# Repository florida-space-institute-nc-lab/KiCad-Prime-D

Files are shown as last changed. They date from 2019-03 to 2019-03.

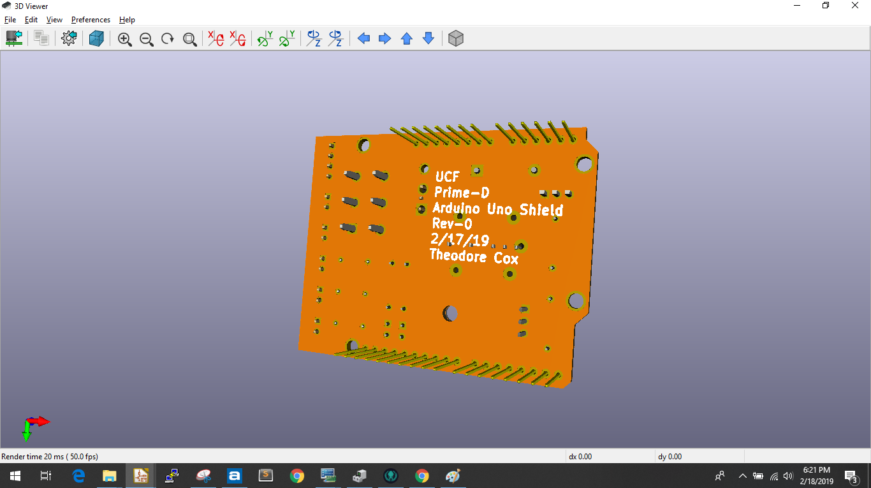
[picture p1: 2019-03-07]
documents/pictures/3dView_021819_1.png

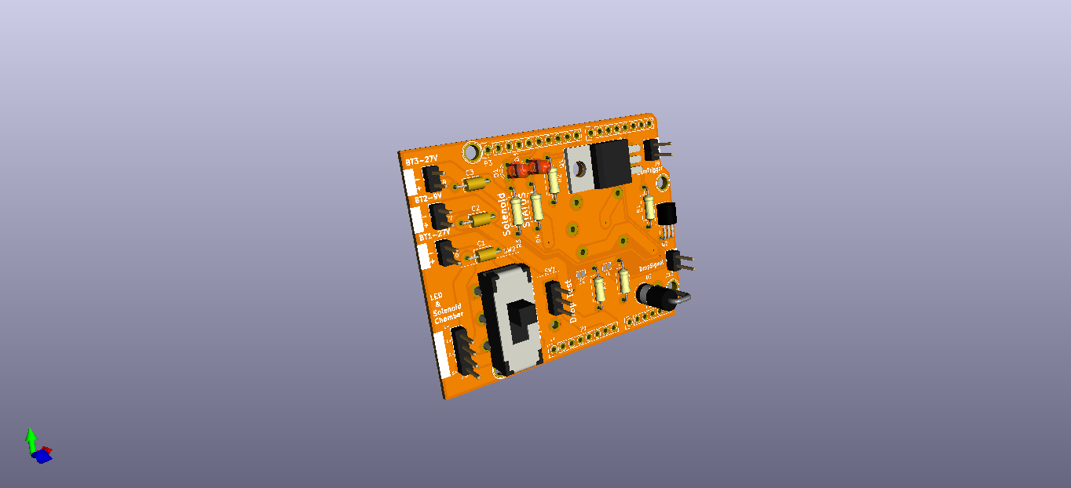
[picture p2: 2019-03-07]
documents/pictures/3dView_021819_3.png

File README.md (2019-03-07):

# Prime-D
This KiCad project includes both the schematic and pcb-layout for FSI drop tower project "Prime-D".  This circuit board should be treated as an Arduino "Shield" and be placed on top of the Arduino Uno socket.



## Usage
This project requires KiCad Version 5.0 and after to use.

## Documents Folder
The documents folder contains;
  * [the bill of materials (BOM)](/KiCad%20Projects/PRIME-D/documents/BOM/)
  * [all of the components datasheets](/KiCad%20Projects/PRIME-D/documents/datasheets/)
  * [gerber files](/KiCad%20Projects/PRIME-D/documents/Gerbers/)
  * [pictures](/KiCad%20Projects/PRIME-D/documents/pictures/)
  * [previous revisions](/KiCad%20Projects/PRIME-D/documents/Revisions/)
  * [pdf of both the schematic and pcb layout](/KiCad%20Projects/PRIME-D/documents/schematic_n_PCBlayout/)

## Coming Soon
Again please note that this Prime-D circuit board should be treated as an Arduino Uno shield.  The software to program the arduino will be added to this repo soon.

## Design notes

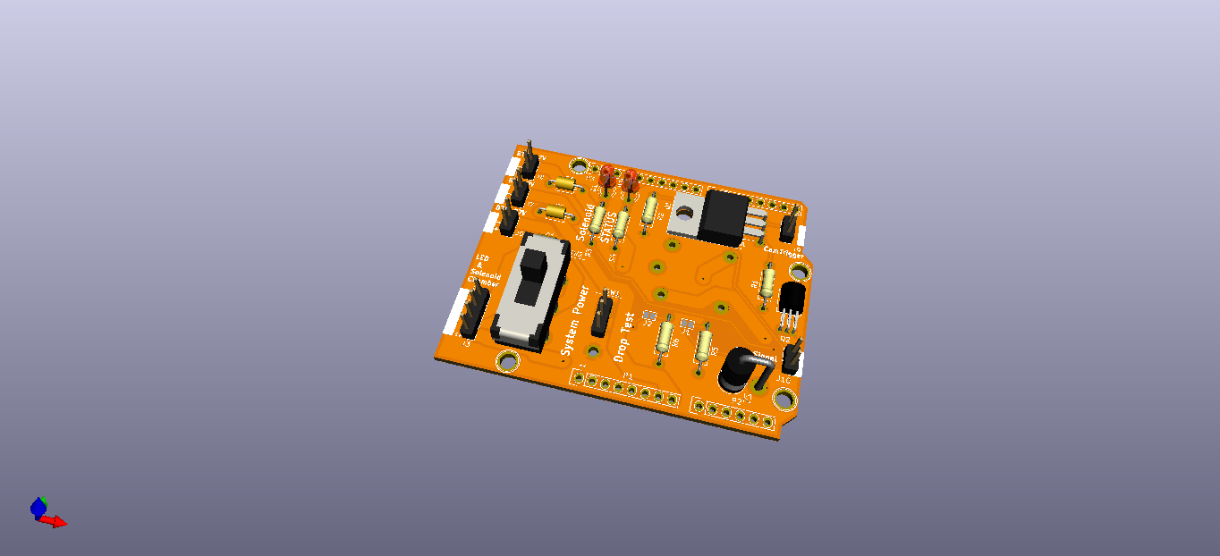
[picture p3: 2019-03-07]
documents/pictures/3dView_021819_2.png

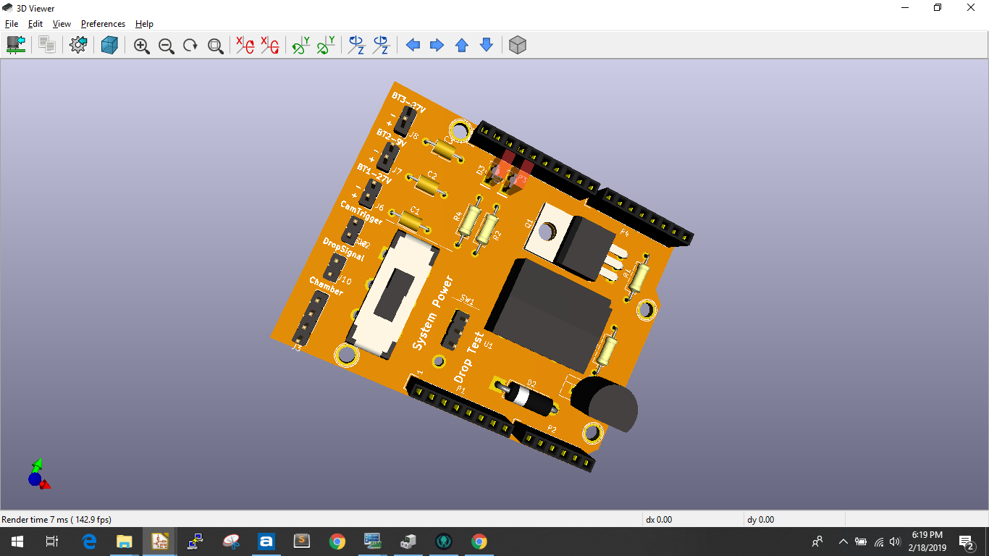
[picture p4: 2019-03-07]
documents/pictures/3dView_021819_0.png

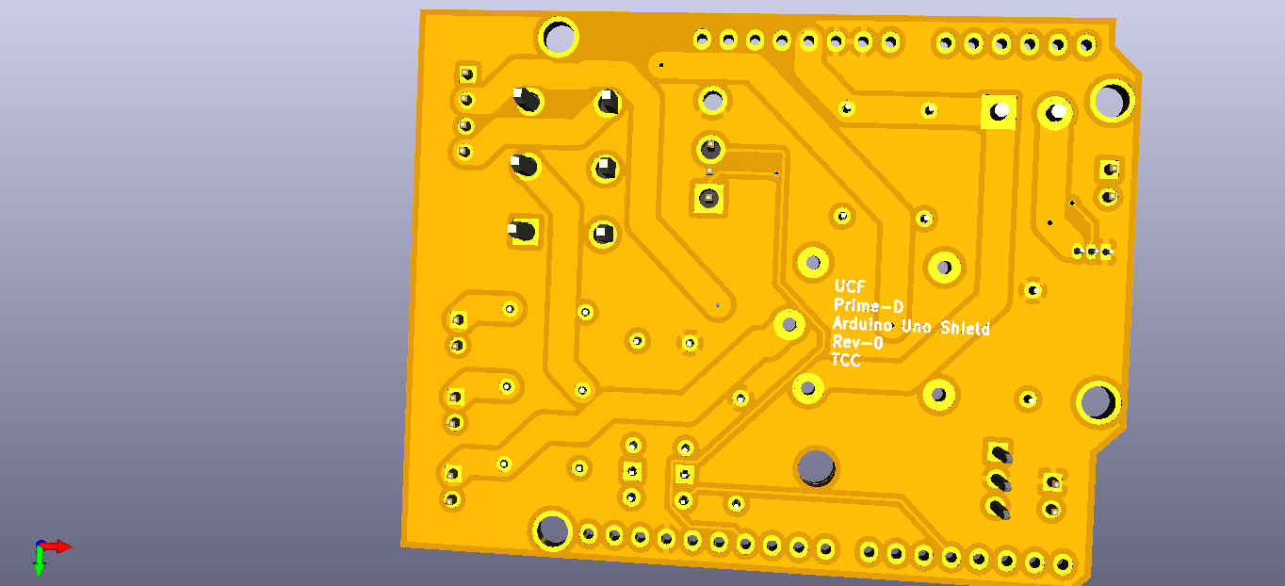
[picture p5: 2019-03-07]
documents/pictures/3dView_021819_4.png

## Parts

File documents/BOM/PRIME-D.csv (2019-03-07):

Title | PRIME D
Revision
Date | 2019-02-13
Generated | 2/18/2019 8:06:50 PM
Company | CMR
Comment 1 | This schematic was created after prototype board was created.
Comment 2 | This is only the KiCad author's interpretation of the electrical design of Prime-D.
Comment 3 | Author - Theodore Cox
Comment 4 | Date - 2/13/19
Total Parts | 33
Total Unique Parts | 23
Ref | Qty | Value | Footprint | Datasheet
C1 C2 C3 | 3 | 1uF | Capacitors_THT:C_Axial_L3.8mm_D2.6mm_P7.50mm_Horizontal | ~
D1 D3 | 2 | LED | LEDs:LED_D3.0mm | ~
D2 | 1 | 1N4007 | Diodes_THT:D_DO-201AD_P5.08mm_Vertical_AnodeUp | ~
J1 J2 | 2 | GS2 | Connectors:GS2
J3 | 1 | Connector_Chamber | Connector_PinHeader_2.54mm:PinHeader_1x04_P2.54mm_Vertical | ~
J6 | 1 | BAT1_27V | Connector_PinHeader_2.54mm:PinHeader_1x02_P2.54mm_Vertical | ~
J7 | 1 | BAT2_9V | Connector_PinHeader_2.54mm:PinHeader_1x02_P2.54mm_Vertical | ~
J8 | 1 | BAT3_27V | Connector_PinHeader_2.54mm:PinHeader_1x02_P2.54mm_Vertical | ~
J9 | 1 | CameraTrigger | Connector_PinHeader_2.54mm:PinHeader_1x02_P2.54mm_Vertical | ~
J10 | 1 | DropSignal | Connector_PinHeader_2.54mm:PinHeader_1x02_P2.54mm_Vertical | ~
K1 | 1 | ORWH-SH-105D1F | 000 | primeD-kiCad_pcbfootprints:Relay_SPST_ORWH-SH-105D1F | 000 | https://www.omron.com/ecb/products/pdf/en-g5q.pdf
P1 | 1 | Power | Socket_Arduino_Uno:Socket_Strip_Arduino_1x08
P2 | 1 | Analog | Socket_Arduino_Uno:Socket_Strip_Arduino_1x06
P3 | 1 | Digital | Socket_Arduino_Uno:Socket_Strip_Arduino_1x10
P4 | 1 | Digital | Socket_Arduino_Uno:Socket_Strip_Arduino_1x08
P5 P6 P7 P8 | 4 | CONN_01X01 | Socket_Arduino_Uno:Arduino_1pin
Q1 | 1 | IRLI3705N | TO_SOT_Packages_THT:TO-220-3_Horizontal | ~
Q2 | 1 | NPN-2N2222 | TO_SOT_Packages_THT:TO-92_Horizontal1_Inline_Narrow_Oval | http://www.onsemi.com/pub_link/Collateral/2N2219-D.PDF
R1 R2 R5 R6 | 4 | 100K | Resistors_THT:R_Axial_DIN0207_L6.3mm_D2.5mm_P10.16mm_Horizontal | CF14JT100K
R3 | 1 | 150 | Resistors_THT:R_Axial_DIN0207_L6.3mm_D2.5mm_P10.16mm_Horizontal | ~
R4 | 1 | 150 | Resistors_THT:R_Axial_DIN0207_L6.3mm_D2.5mm_P10.16mm_Horizontal | CF14JT150R
SW1 | 1 | RED-SW_Push_SPDT | primeD-kiCad_pcbfootprints:SPDT_4.7mm | JS102011JCQN
SW2 | 1 | SW_DPDT_x2 | primeD-kiCad_pcbfootprints:DPDT_Pitch7-62x6-35mm | S202031MS02Q
BOM made with KICAD_BOM_WIZARD (https://github.com/HashDefineElectronics/KiCad_BOM_Wizard.git)
Generated 2/18/2019 8:06:50 PM

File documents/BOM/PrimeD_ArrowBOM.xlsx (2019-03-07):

REF Value | Requested Quantity | Part Number
C1 C2 C3 | 3 | TVX2A010MAD (https://www.arrow.com/en/products/tvx2a010mad/nichicon/)
D1 | 1 | VAOL-3GAE4 (https://www.arrow.com/en/products/vaol-3gae4/visual-communications/)
D3 | 1 | LTH3MM12VFR4500 (https://www.arrow.com/en/products/lth3mm12vfr4500/visual-communications/)
D2 | 1 | 1N4007 (https://www.arrow.com/en/products/1n4007/good-ark-semiconductor/)
K1 | 1 | ORWH-SH-105D1F,000 (https://www.arrow.com/en/products/orwh-sh-105d1f000/te-connectivity/)
Q1 | 1 | IRLI3705NPBF (https://www.arrow.com/en/products/irli3705npbf/infineon-technologies-ag/)
Q2 | 1 | 2N2222A (https://www.arrow.com/en/products/2n2222a/diotec-semiconductor-ag/)
R1 R2 R5 R6 | 4 | CF14JT100K (https://www.arrow.com/en/products/cf14jt100k/stackpole-electronics/)
R3 R4 | 2 | CF14JT150R (https://www.arrow.com/en/products/cf14jt150r/stackpole-electronics/)
SW1 | 1 | MFP 106 D (https://www.arrow.com/en/products/mfp106d/knitter-switch/)
SW2 | 1 | S202031MS02Q (https://www.arrow.com/en/products/s202031ms02q/ck/)
J? | 2 | AW140-EG-G36D (https://www.arrow.com/en/products/aw140-eg-g36d/assmann-wsw-components-inc/)

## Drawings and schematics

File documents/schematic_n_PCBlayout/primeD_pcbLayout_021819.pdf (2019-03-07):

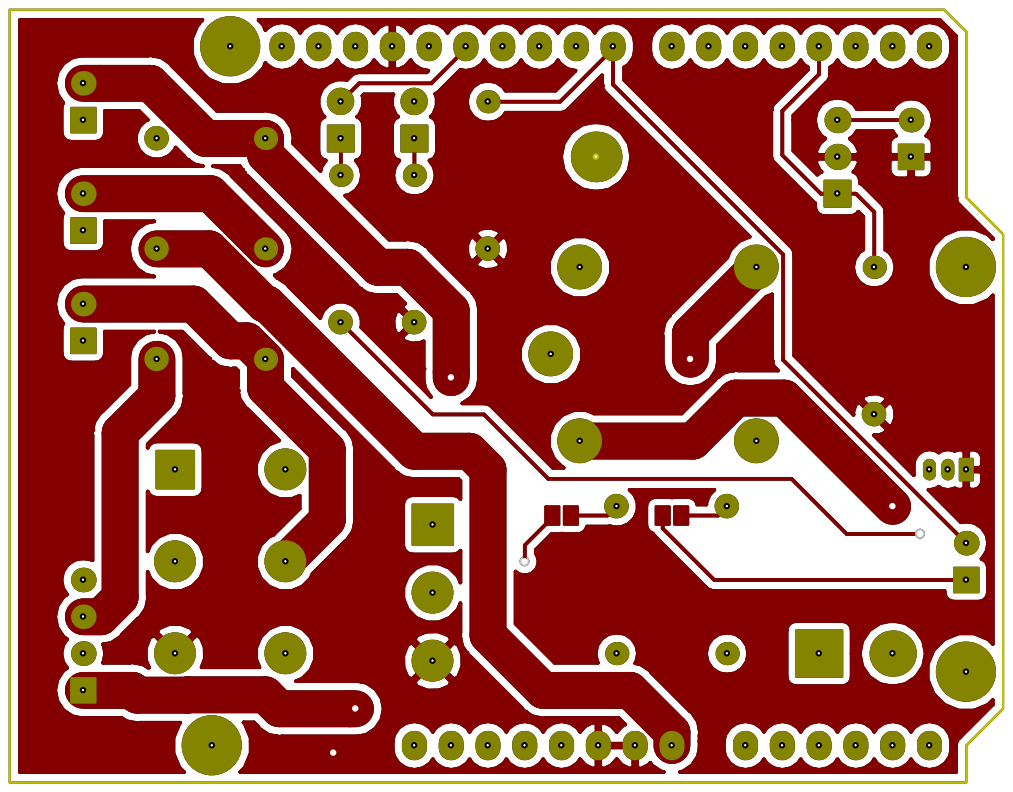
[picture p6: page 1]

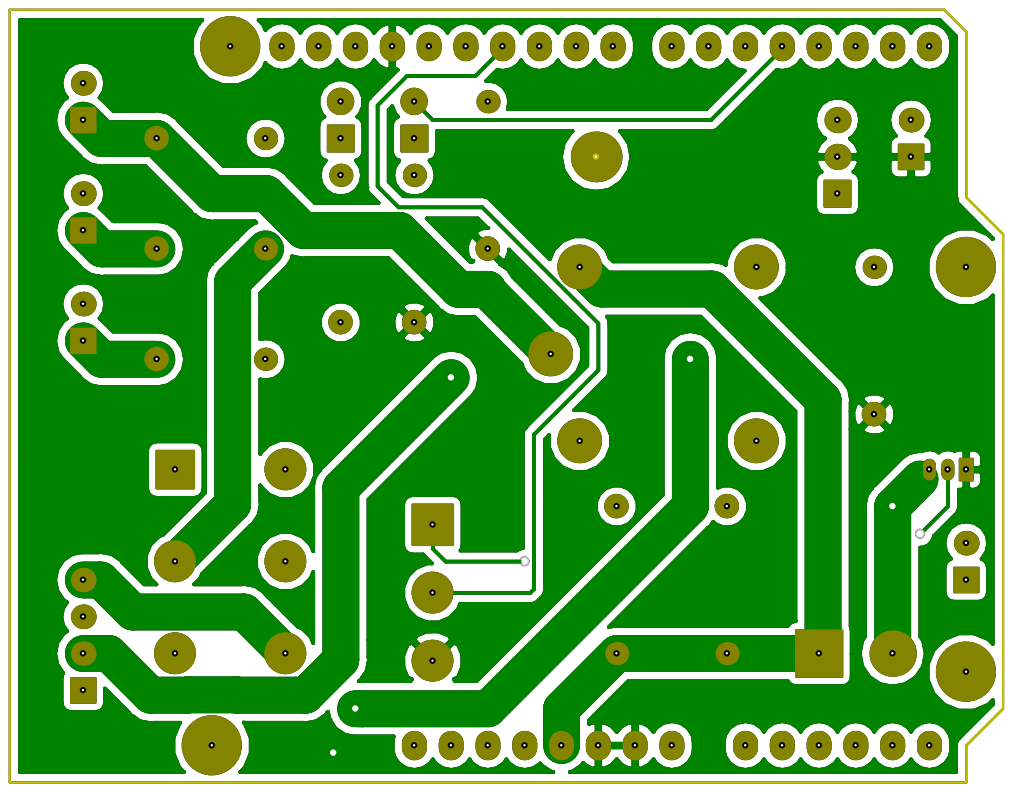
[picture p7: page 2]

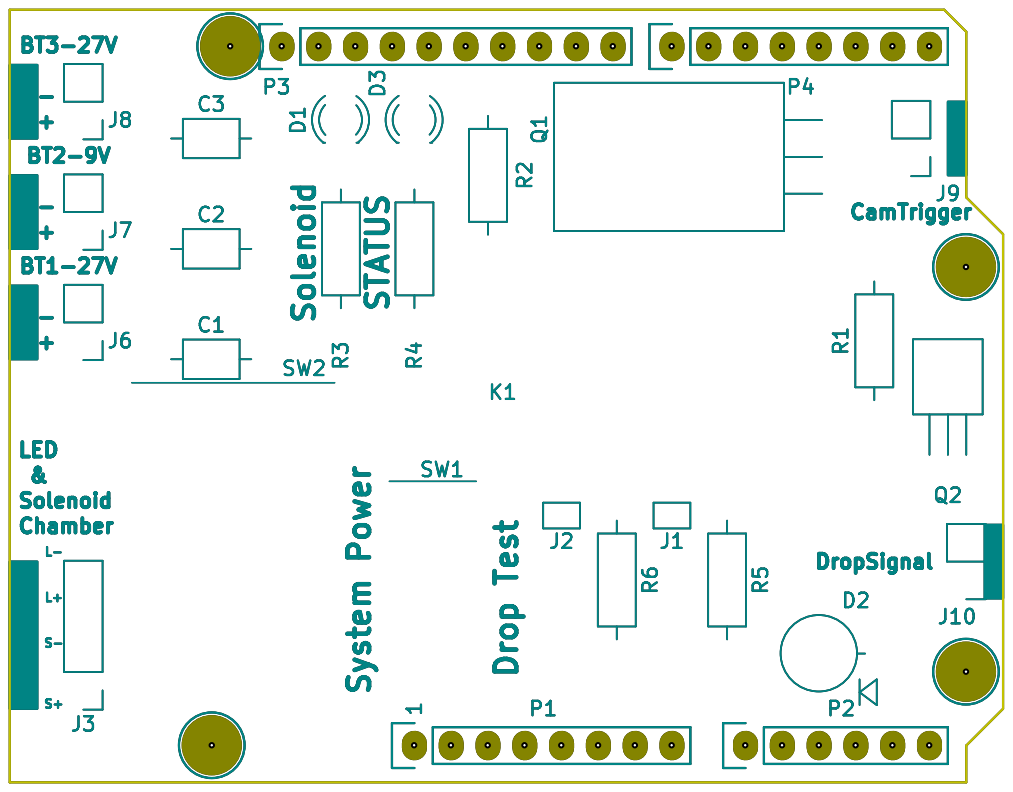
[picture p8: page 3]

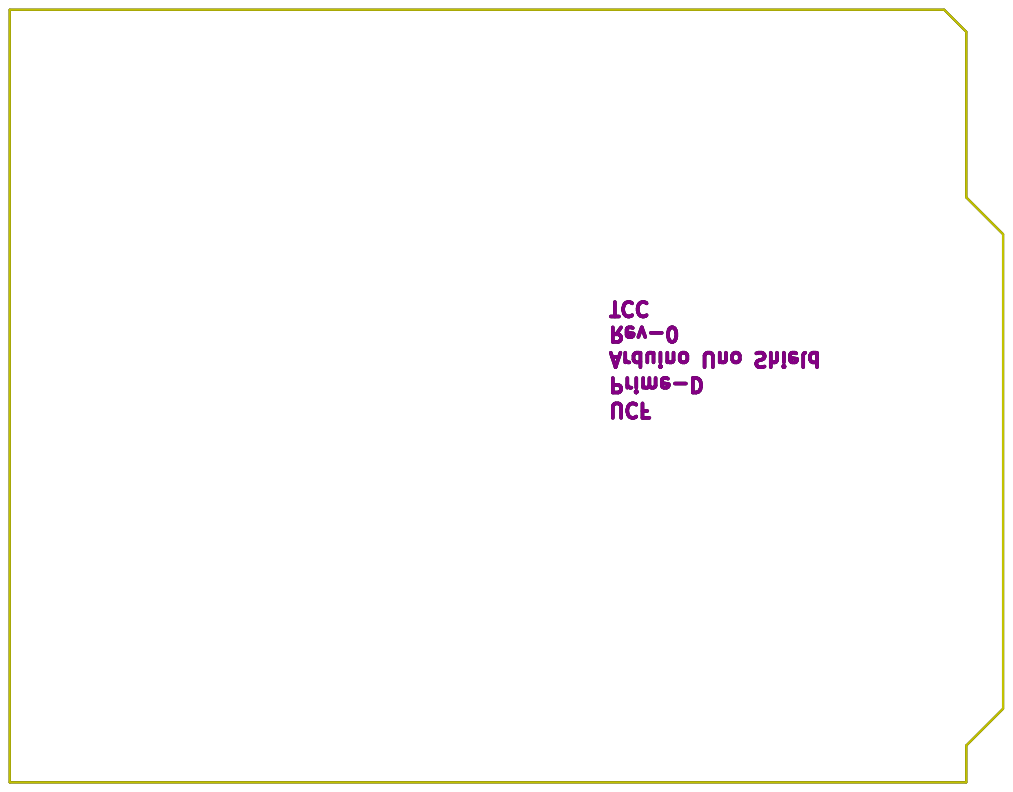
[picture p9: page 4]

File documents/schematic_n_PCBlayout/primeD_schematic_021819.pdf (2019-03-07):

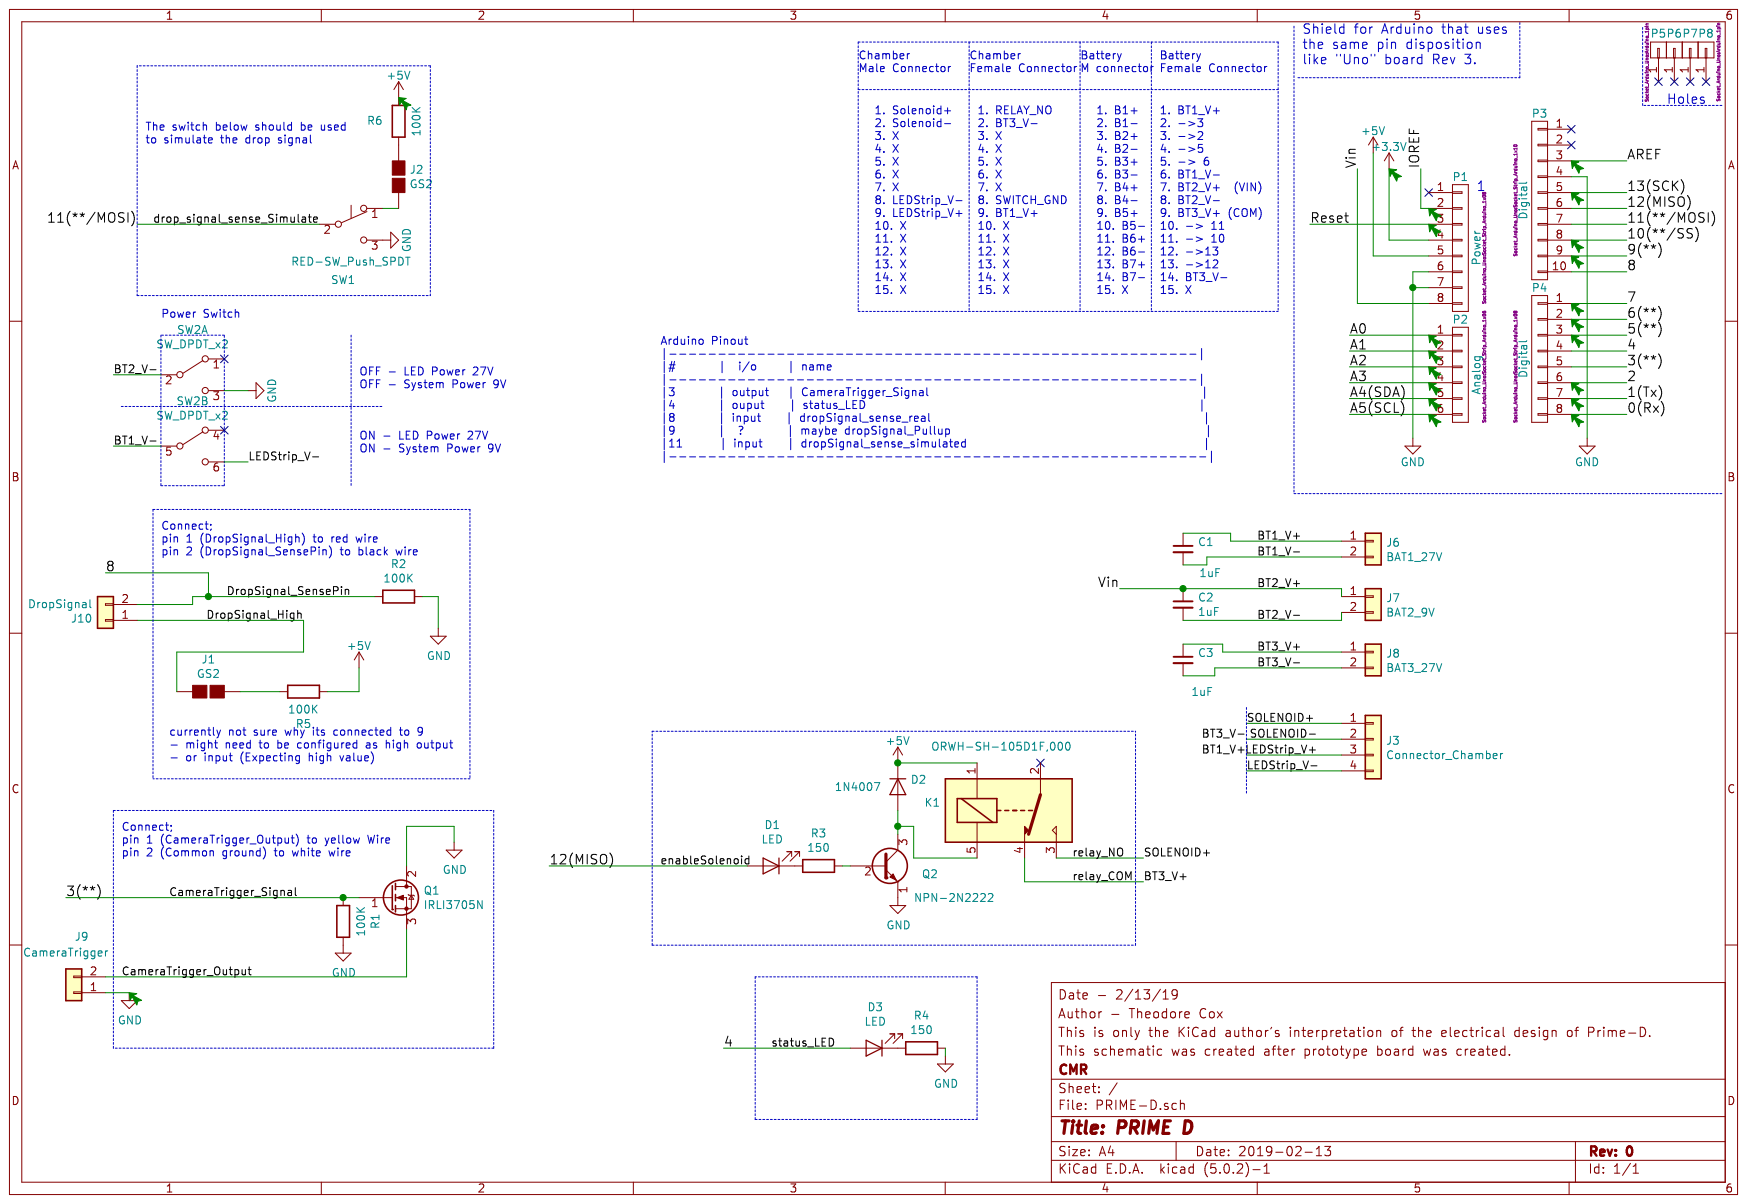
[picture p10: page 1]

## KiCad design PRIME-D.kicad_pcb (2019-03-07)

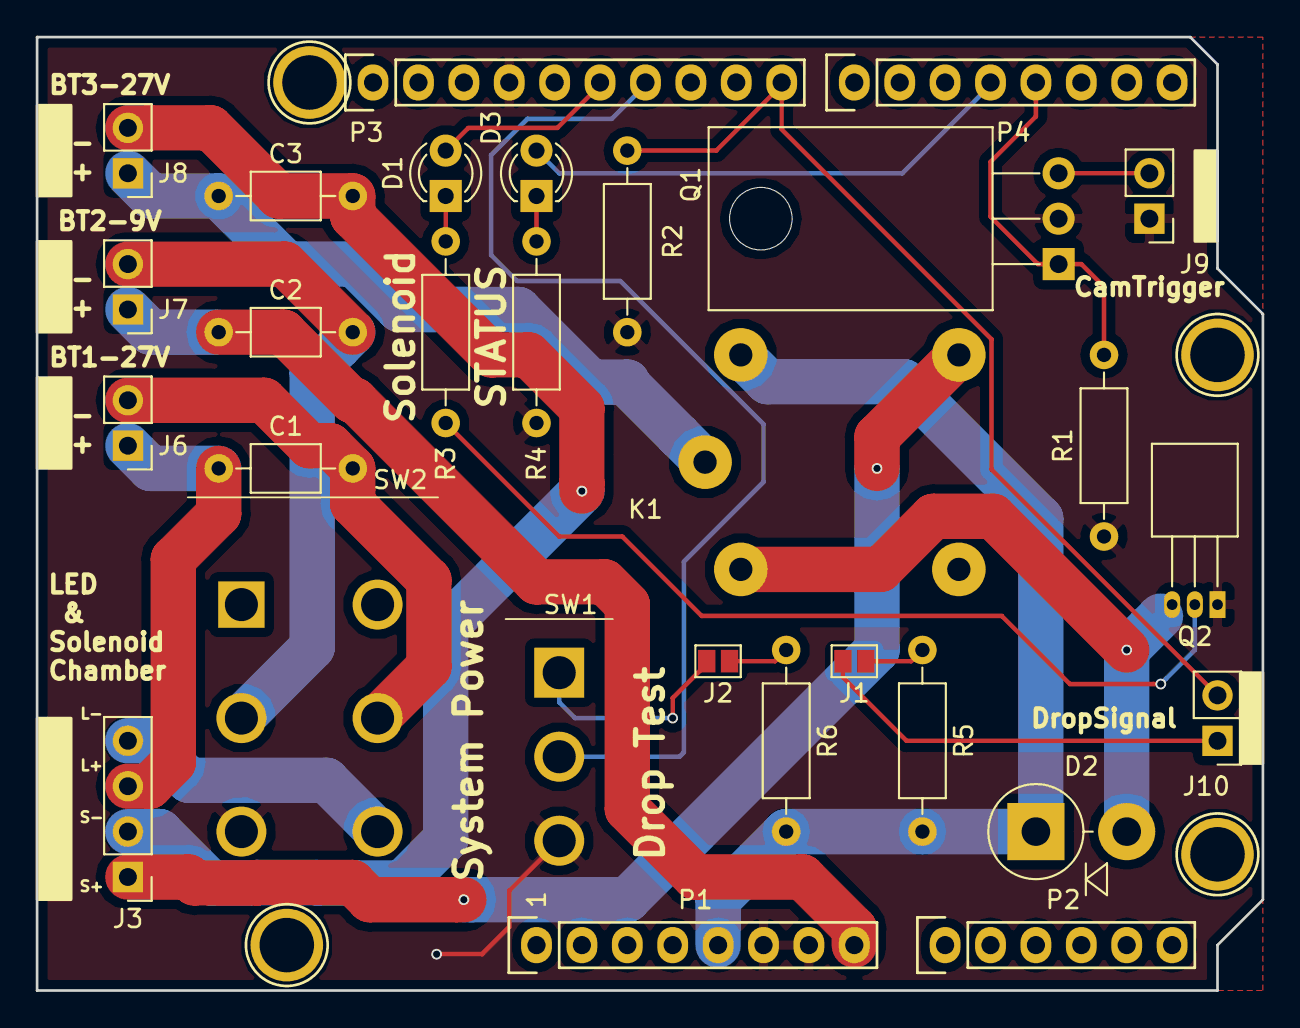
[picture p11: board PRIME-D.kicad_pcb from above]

Board: 2 copper layers, 68.6 x 53.3 mm, 33 parts (0 on the bottom side), 24 nets.

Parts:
C1, C2, C3: 1uF; C_Axial_L3.8mm_D2.6mm_P7.50mm_Horizontal
D1, D3: LED; LED_D3.0mm
D2: 1N4007; D_DO-201AD_P5.08mm_Vertical_AnodeUp
J1, J2: GS2
J3: Connector_Chamber; PinHeader_1x04_P2.54mm_Vertical
J6: BAT1_27V; PinHeader_1x02_P2.54mm_Vertical
J7: BAT2_9V; PinHeader_1x02_P2.54mm_Vertical
J8: BAT3_27V; PinHeader_1x02_P2.54mm_Vertical
J9: CameraTrigger; PinHeader_1x02_P2.54mm_Vertical
J10: DropSignal; PinHeader_1x02_P2.54mm_Vertical
K1: ORWH-SH-105D1F,000; Relay_SPST_ORWH-SH-105D1F,000
P1: Power; Socket_Strip_Arduino_1x08
P2: Analog; Socket_Strip_Arduino_1x06
P3: Digital; Socket_Strip_Arduino_1x10
P4: Digital; Socket_Strip_Arduino_1x08
P5, P6, P7, P8: CONN_01X01; Arduino_1pin
Q1: IRLI3705N; TO-220-3_Horizontal
Q2: NPN-2N2222; TO-92_Horizontal1_Inline_Narrow_Oval
R1, R2, R5, R6: 100K; R_Axial_DIN0207_L6.3mm_D2.5mm_P10.16mm_Horizontal
R3, R4: 150; R_Axial_DIN0207_L6.3mm_D2.5mm_P10.16mm_Horizontal
SW1: RED-SW_Push_SPDT; SPDT_4.7mm
SW2: SW_DPDT_x2; DPDT_Pitch7-62x6-35mm

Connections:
+5V: D2.1, K1.1, P1.5, R5.2, R6.2
/3(**): P4.5, Q1.1, R1.2
/4: D3.2, P4.4
/8: J10.2, P3.10, R2.2
/11(**/MOSI): P3.7, SW1.2
/12(MISO): D1.2, P3.6
/BT1_V+: C1.1, J3.3, J6.1
/BT1_V-: C1.2, J6.2, SW2.5
/BT2_V+: C2.1, J7.1, P1.8
/BT2_V-: C2.2, J7.2, SW2.2
/BT3_V+: C3.1, J8.1, K1.4
/BT3_V-: C3.2, J3.2, J8.2
/CameraTrigger_Output: J9.2, Q1.3
/DropSignal_High: J1.2, J10.1
/LEDStrip_V-: J3.4, SW2.6
/SOLENOID+: J3.1, K1.3
GND: J9.1, P1.6, P1.7, P3.4, Q1.2, Q2.1, R1.1, R2.1, R4.1, SW1.3, SW2.3
unnamed: D1.1, R3.2
unnamed: D2.2, K1.5, Q2.3
unnamed: D3.1, R4.2
unnamed: J1.1, R5.1
unnamed: J2.1, R6.1
unnamed: J2.2, SW1.1
unnamed: Q2.2, R3.1
